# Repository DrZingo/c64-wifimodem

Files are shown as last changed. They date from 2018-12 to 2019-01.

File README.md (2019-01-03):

# c64-wifimodem

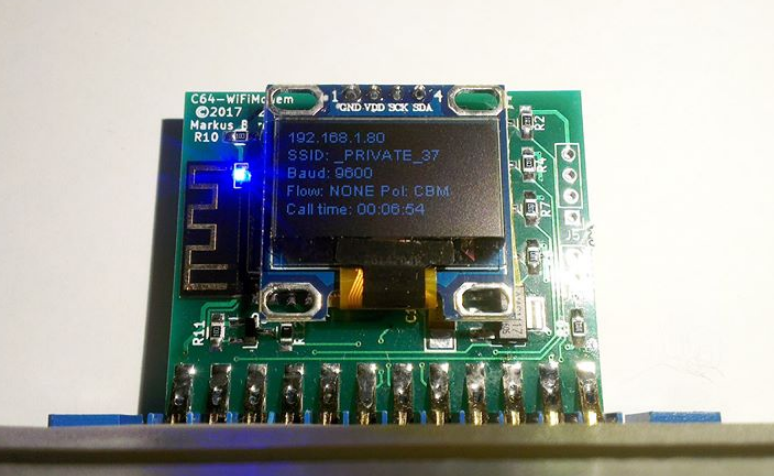
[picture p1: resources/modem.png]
modem


## src
Source code for my c64-wifimodem

Feel free to make changes and correction.

## Important
- Please change example.com to your own domain for OTA updates. 
- You will also have to create a backend for OTA to work.

## Stuff that needs work
- Changing pin polarity does not work as expected.
  - V-1541 and commodoreserver.com should work if implemented correct. I had it working, but then normal cbm polarity didn't work as it should.
- Higher baud rates
  - 19200 and 38400 will work but is only used with flipped polarity as I know of.
- Incoming calls
  - I am not enough familiar with bbs servers answering mechanism, and couldn't get it to work with my badly set up bbs server.
  - Direct call connection to the modem does work, sort of.
- S-registers
  - May be useful, I don't know.

## c64-wifimodem
PCB files in kicad format. Nothing much to say about it.

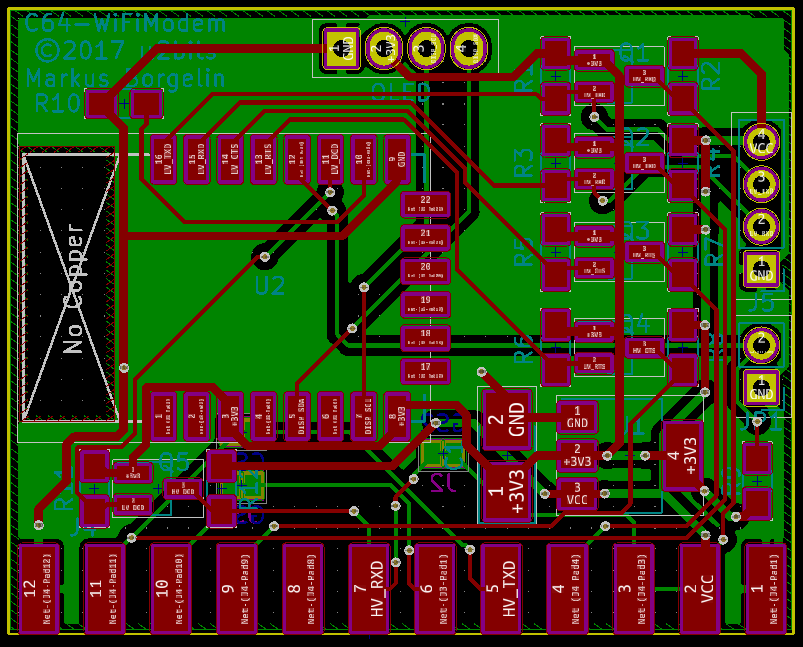
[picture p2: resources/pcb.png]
pcb


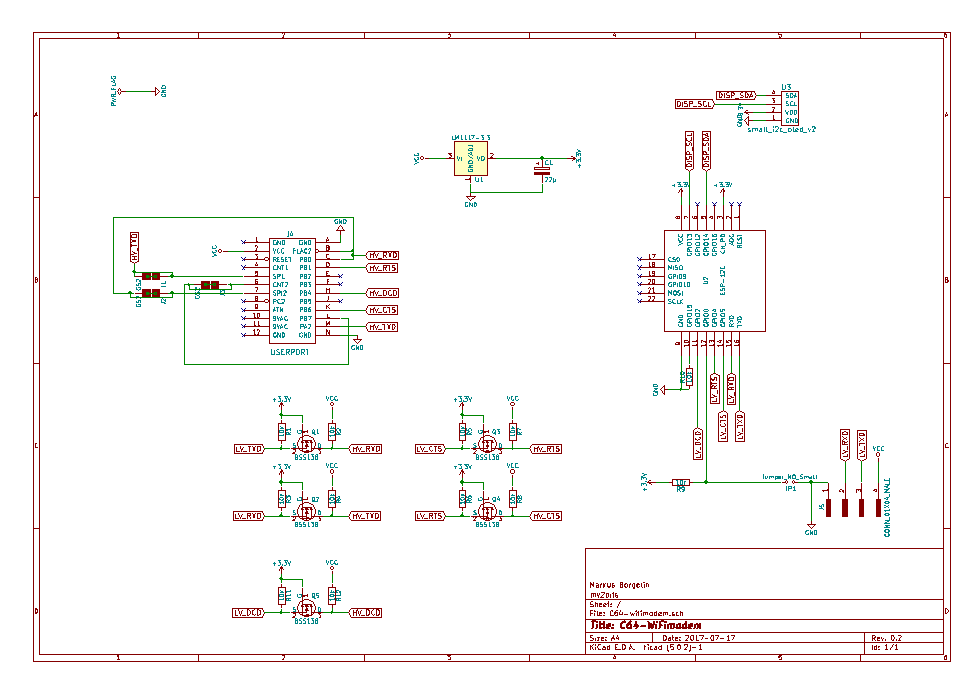
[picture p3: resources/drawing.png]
schematic


## BOM

```
 C1      Tantalum 22uF Case B, 3528
 J4      User Port edge connector
 Q1-Q5   BSS138 SOT-23
 R1-R12  10k 0805
 U1      LM1117-3.3 SOT-223
 U2      ESP8266 12E or 12F
 U3      OLED 0.96" GND,VCC,SCL,SDA
```

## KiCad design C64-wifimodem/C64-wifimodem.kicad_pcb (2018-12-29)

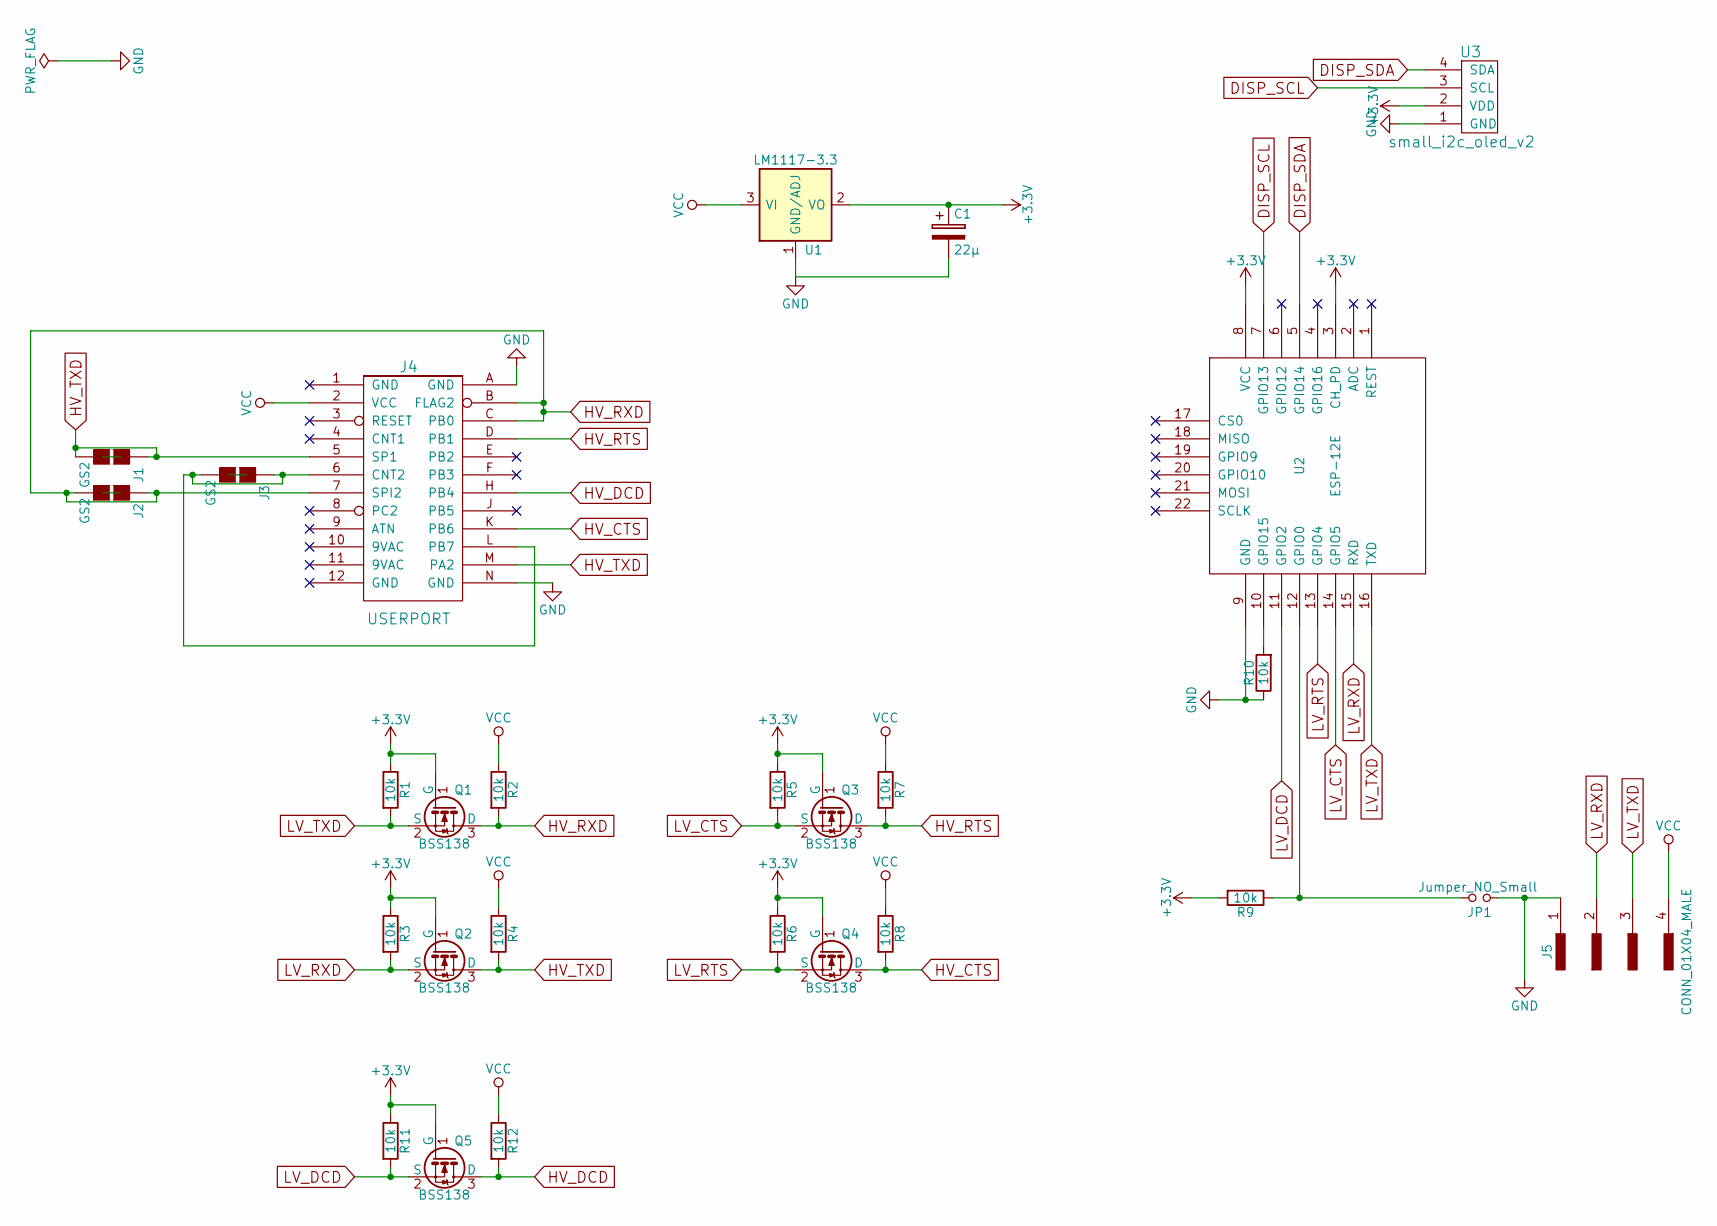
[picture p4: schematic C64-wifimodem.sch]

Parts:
C1: 22µ; CP_Tantalum_Case-B_EIA-3528-21_Hand
J1, J2, J3: GS2
J4: USERPORT
J5: CONN_01X04_MALE; Pin_Header_Straight_1x04_Pitch2.54mm
JP1: Jumper_NO_Small; Pin_Header_Straight_1x02_Pitch2.54mm
Q1, Q2, Q3, Q4, Q5: BSS138; SOT-23_Handsoldering
R1, R2, R3, R4, R5, R6, R7, R8, R9, R10, R11, R12: 10k; R_0805_HandSoldering
U1: LM1117-3.3; SOT-223
U2: ESP-12E; ESP-12E_SMD_wo_line
U3: small_i2c_oled_v2; Small_I2C_OLED_v2

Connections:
+3V3: C1.1, Q1.1 (G), Q2.1 (G), Q3.1 (G), Q4.1 (G), Q5.1 (G), R1.1, R3.1, R5.1, R6.1, R9.2, R11.1, U1.2 (VO), U1.4 (VO), U2.3 (CH_PD), U2.8 (VCC), U3.2 (VDD)
DISP_SCL: U2.7 (GPIO13), U3.3 (SCL)
DISP_SDA: U2.5 (GPIO14), U3.4 (SDA)
GND: C1.2, J4.A (GND), J4.N (GND), J5.1, JP1.1, R10.1, U1.1 (GND/ADJ), U2.9 (GND), U3.1 (GND)
HV_CTS: J4.K (PB6), Q4.3 (D), R8.2
HV_DCD: J4.H (PB4), Q5.3 (D), R12.2
HV_RTS: J4.D (PB1), Q3.3 (D), R7.2
HV_RXD: J2.1 (G1), J2.2 (G2), J4.7 (SPI2), J4.B (FLAG2), J4.C (PB0), Q1.3 (D), R2.2
HV_TXD: J1.1 (G1), J1.2 (G2), J4.5 (SP1), J4.M (PA2), Q2.3 (D), R4.2
LV_CTS: Q3.2 (S), R5.2, U2.14 (GPIO5)
LV_DCD: Q5.2 (S), R11.2, U2.11 (GPIO2)
LV_RTS: Q4.2 (S), R6.2, U2.13 (GPIO4)
LV_RXD: J5.2, Q2.2 (S), R3.2, U2.15 (RXD)
LV_TXD: J5.3, Q1.2 (S), R1.2, U2.16 (TXD)
unnamed: J3.1 (G1), J3.2 (G2), J4.6 (CNT2), J4.L (PB7)
unnamed: JP1.2, R9.1, U2.12 (GPIO0)
unnamed: R10.2, U2.10 (GPIO15)
VCC: J4.2 (VCC), J5.4, R2.1, R4.1, R7.1, R8.1, R12.1, U1.3 (VI)

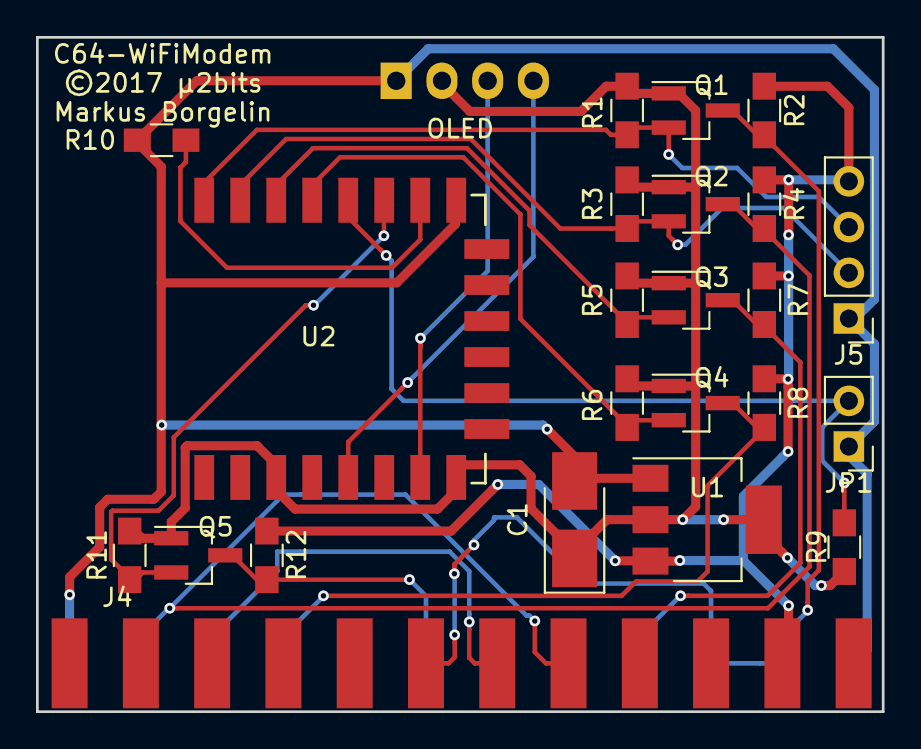
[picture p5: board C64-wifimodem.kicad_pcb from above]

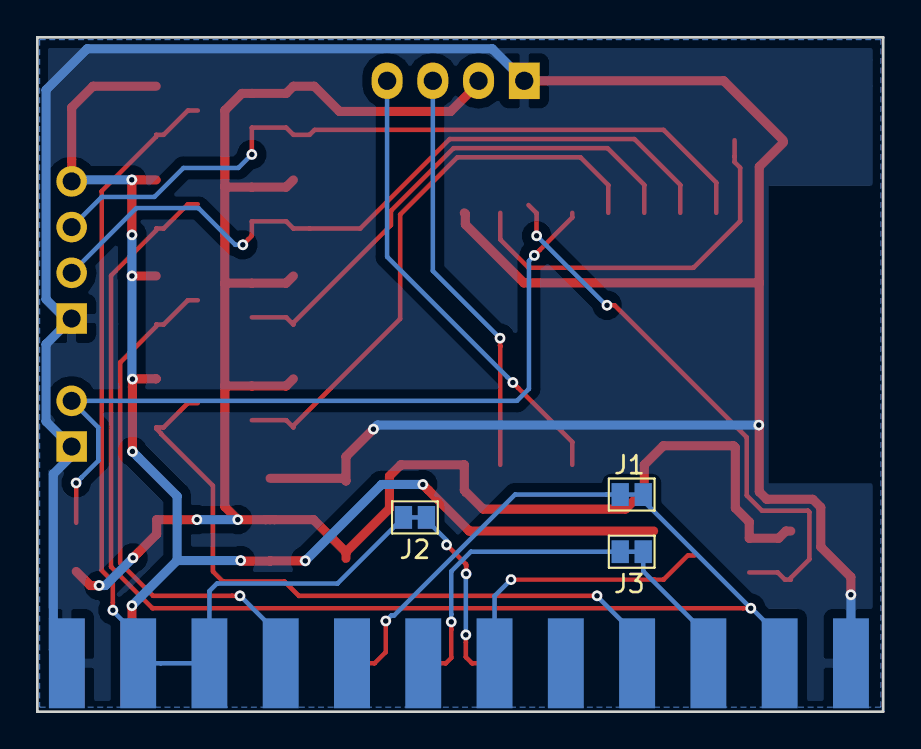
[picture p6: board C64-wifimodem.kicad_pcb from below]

Board: 2 copper layers, 47.0 x 37.5 mm, 27 parts (3 on the bottom side), 18 nets.

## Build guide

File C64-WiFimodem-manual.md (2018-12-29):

# C64-WiFimodem instructions

This is a WiFi modem for your Commodore 64 and the modern era of internet connectivity.

## Release history
2017-12-01 (online manual update)
* Added info for unencrypted WiFi

2017-09-16 (v0.1.9)
* Small typo correction. Update not necessary

2017-09-09 (online manual update)
* Added 'Hints and Tips' to manual

2017-09-06 (online manual update)
* Added pre-0.1.8 notice to 'Configure WiFi' section in manual

2017-08-30 (v0.1.8 - First release)
* The first available firmware loaded with features.
* Polarity is very experimental at the moment, and your modem will most probably stop responding if you change it. It will not harm your modem nor your computer, but you will have to reboot.
* To have a BBS Server, you will probably need RI-signal, which this modem does not supply. I will have to look further into this. But you can call from one terminal to another, i.e. someone calls you at your server port while you are in a terminal.

## Installation
1. First power off your Commodore. 
2. Plug C64-WiFimodem in the User Port of your C64.
3. Start your C64 and load a terminal program, preferrable [CCGMS 2017 V6], which is the terminal supported by this modem.
4. Now you should see the modem display telling you to press Return.
5. Change your terminal to ASCII mode and 300 baud. 

   Press ```F7``` to enter CCGMS settings.  
   Press ```B``` a couple of times until baud shows '300'.  
   Then press ```RETURN``` to go back to terminal mode.  
   Back in terminal mode you press ```F8``` (Shift+F7) to change to Anscii.
6. Press ```RETURN```, and you should see a welcome message in your C64 terminal.
7. type ```AT?``` and you should see some help.

## Configure WiFi

First type
```
AT$SCAN<RETURN>
```
to see all avaliable WiFi networks

Be aware that some characters show up differently on your Commodore screen. For instance underscore ```'_'``` will show up as left arrow ```'⬅'```. This is also how you have to type it in on your Commodore.

Then type
```
AT$SSID=<Your SSID here as shown in the SCAN listing><RETURN>
AT$PASS=<Your SSID password here><RETURN>
```
If you are connecting to a WiFi without encryption, just put anything in AT$PASS, it can not be empty. E.g. ```AT$PASS=123```

Now type
```
AT$C1<RETURN>
```
pre-0.1.8 use ATC1 instead
```
ATC1<RETURN>
```
and the modem will try to connect to the specified router. It may fail to connect the first time which is normal. Just try again, and if it won't connect, check for typos in your SSID or password.

Now when you have connected, you can save your settings with
```
AT&W<RETURN>
```
The modem will now try to connect to this network every time you start your Commodore and send the first ```RETURN``` to it.

## Extra configuration

If you prefer to have for example 2400 baud at startup, follow these commands:
```
AT$SB=2400<RETURN>
```
This will change the modem to 2400 baud. Now press ```F7``` to go to Terminal settings. 
Change terminal baud-rate with ```B``` to 2400. You may also have to change "Modem Type" to either "User Port 300-2400" or "UP9600" with ```M``` a couple of times. I use UP9600 most of the time.
Now press ```<RETURN>``` to go back to Terminal Mode.
Test with
```
AT<RETURN>
```
You will see "OK". If there was some garbage in the buffer it will give you "ERROR". Just try again.
Now type
```
AT&W
```
This will store your settings to the modem. Then press ```F7``` again and then ```S``` to save your terminal settings.

## Hints and Tips

If you experience graphics tearing in UP9600 mode, you can try using hardware handshake.
In offline mode type:
```
at&k1<RETURN>
```
Or in online mode type:
```
+++ (NO RETURN, wait for 'ok', and you are in cmd mode)
at&k1<RETURN>
ato<RETURN> (going back to online mode)
```
If you experience lockups while changing baud rates, always set UP9600 as modem type first. You can use UP9600 for 300-9600 baud, so there is no need to use other modem types.
Press ```<F7>``` to enter CCGMS settings.
Press ```M``` to set UP9600.
Press ```RETURN``` to go back to terminal mode.

Please have hardware handshaking off, while changing baudrate, and preferrable be in Graphics mode, not Anscii. This will minimize possible modem lockups.
Example:
```
at&k0<RETURN>
<F8 to get to Graphics mode>
at$sb=9600
at&k1<RETURN>
```

## Commands

| DIALING COMMANDS | Explanation | Example |
| --- | --- | --- |
| ATDTHOST:PORT | Dial a host | ```ATDTBBS.RETROHACK.SE:6464``` |
| ATDSN (0-9) | Dial a stored host | ```ATDS1``` |
| AT&ZN=HOST:PORT | Store a host and port to speed dials where N is a number from 0 to 9 | ```AT&Z1=BBS.RETROHACK.SE:6464``` |
| ATH | Hangup from a connected call | ```ATH``` |
| +++ | Enter command mode from online mode | ```+++``` |
| ATO | Exit command mode and go to online mode again | ```ATO``` |

| SERVER COMMANDS | Explanation | Example |
| --- | --- | --- |
| ATA | Answer an incoming call manually | ```ATA``` |
| AT$SP=N | Set the port where callers will reach you | ```AT$SP=6400``` |
| ATS0/ATS1 | Set auto answer, OFF/ON | ```ATS0``` |
| AT$BM=MESSAGE | Set the message that callers will see when your server is busy | ```AT$BM=SORRY, THE SERVER IS CURRENTLY BUSY. PLEASE TRY LATER.``` |

| INFO | Explanation | Example |
| ---- | --- | --- |
| ATI | Show modem info | ```ATI``` |

| GENERAL SETTINGS | Explanation | Example |
| --- | --- | --- |
| AT$SB=N (300-38400) | Set the modem baud rate | ```AT$SB=2400``` |
| AT&PN (0=CBM,1=NORM) | Set the pin polarity to commodore or normal | ```AT&P0``` |
| AT&KN (0=NONE,1=HW) | Set the flow control to none or hardware | ```AT&K0``` |
| ATE0/ATE1 | Set the modem to echo back to terminal, OFF/ON | ```ATE1``` |
| ATV0/ATV1 | Set verbose modem responds, OFF/ON | ```ATV1``` |
| ATZ | Load settings from flash | ```ATZ``` |
| AT&W | Write current settings to flash | ```AT&W``` |
| AT&V | View current and stored settings | ```AT&V``` |
| AT&F | Restore modem to factory defaults | ```AT&F``` |

| WIFI SETTINGS | Explanation | Example |
| --- | --- | --- |
| AT$C0/AT$C1 | Disconnect from wifi / Connect to wifi | ```AT$C1``` (old firmware ```ATC1``` and ```ATC0```) |
| AT$SSID=[SSID] | Set the wifi SSID to connect to. The common underscore is a left arrow on c64. See ```HOME_ROUTER``` in example. | ```AT$SSID=HOME⬅ROUTER``` |
| AT$PASS=PASS | Set the wifi password of the SSID you are connecting to. Your terminal have to be in ASCII/Anscii mode, and some characters may show differently in your terminal. For instance, underscore '_' will show as left arrow '⬅'. Some characters may not even work. Give it some trial and error, and if it won't work, please change your routers password to less obscure characters. | ```AT$PASS=S3cr3tP4ssw0rd``` | 
| AT$SCAN | The modem scans for available wifi SSIDs you can connect to. Password enabled networks will have an asterisk (*) suffix. This will show you what characters to enter when setting up with AT$SSID. | ```AT$SCAN``` |

| OTHER COMMANDS | Explanation | Example |
| --- | --- | --- |
| AT$UPDATE | Downloads and updates the firmware to the latest version. Updates will sometimes restore the settings to default values. This happens when an update adds fuctionality that needs to reorganize the stored settings. Please restart your modem after update (```AT$RESTART```).  | ```AT$UPDATE``` |
| AT$RESTART | Restarts the modem and loads the stored settings. Remember to change the terminal settings according to your stored settings afterwards. | ```AT$RESTART``` |
| ATCOMMAND? | Shows the current settings of specified command. | ```AT&K?```  ```ATE?``` |

## License

All files are licensed under GPLv3

---
©2017 µ2bits, Markus Borgelin

[//]: # (Referencer m.m.)

[CCGMS 2017 V6]: <http://csdb.dk/release/?id=156523>

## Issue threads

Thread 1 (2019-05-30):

ESP32 port

kd8bxp, 2019-05-30:
Hi, I just wanted to let you know that I ported the code over to a ESP32 - using a TTGO T-Eight board with OLED (there are at least two different boards called T-Eight from TTGO/LilyGo so depending on which board you have you might need to change/update the OLED pin numbers)
Mostly the code was easy to port and use - I ran into a issue with the telnet server - and it's not working, I'm not real sure how to make that work.
But if you are or anyone is interested in using a ESP32 - this might be a good place to started and fix my port :-)
https://github.com/kd8bxp/c64-wifimodem/tree/esp32
Also, I'm using this to get my Tandy 102 on WiFi, and I think it will also work with my Apple IIc, but I'll have to make a cable for that.
I am planning on making a edge connector to 9 pin serial so I can also use this with my C64. :-)
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

DrZingo, 2019-05-31:
Great!
I hope you get some help with your port. I have no possibility to test myself, and therefore I will not merge it into my repo. Thanks anyway, always great to see the retro scene thrive. :)

kd8bxp, 2019-05-31:
No problem, I understand - I hope someone can help, I'd like to get telnet working. Have a great day, and thanks for original code, and inspiration to build mine.

Closed 2019-05-31.

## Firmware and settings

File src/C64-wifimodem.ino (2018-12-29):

/*
   Change example.com to your needs.
   You will also have to create your own backend for updates.


   C64-WiFiModem - (c) 2017 my2bits <markus at borgelin.org>
   changes here
   Built hardware based on ESP-12, 3.3V-reg and level shifters.
   Tidy up help, and categorizing
   Added automatic firmware check at startup
   Corrected connectWifi() link check
   Changed MAX_CMD_LENGTH to actual FIFO buffer size
   Fixed help-bug in 9600+ baud
   Corrected setBaudRate(), bauds[] array and sizeof, to error out correct
   Adjusted pinouts for my needs
   Adjusted default servers
   Added modem restart command
   Added OLED display with information
   Added OTA Update
   Added scan for wifi
   Some fixes to Pin polarity, does not work as expected though. Fixes welcome
   Probably added more stuff I forgot to write here.
   Thanks to Paul Richards and Jussi Salin for source code.

   based on
   WiFi SIXFOUR - A virtual WiFi modem based on the ESP 8266 chipset
   Copyright (C) 2016 Paul Rickards <rickards@gmail.com>
   Added EEPROM read/write, status/help pages, busy answering of incoming calls
   uses the readily available Sparkfun ESP8266 WiFi Shield which has 5v level
   shifters and 3.3v voltage regulation present-- easily connect to a C64
   https://www.sparkfun.com/products/13287

   based on
   ESP8266 based virtual modem
   Copyright (C) 2016 Jussi Salin <salinjus@gmail.com>

   https://github.com/jsalin/esp8266_modem

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
   You should have received a copy of the GNU General Public License
   along with this program.  If not, see <http://www.gnu.org/licenses/>.
*/

#include <ESP8266WiFi.h>
#include <ESP8266WebServer.h>
#include <EEPROM.h>
#include <ESP8266mDNS.h>

// OTA stuff
//#include <ESP8266WiFiMulti.h>
#include <ESP8266HTTPClient.h>
#include <ESP8266httpUpdate.h>
//ESP8266WiFiMulti WiFiMulti;
// OTA stuff end

// OLED stuff
//#include <Wire.h>  // Only needed for Arduino 1.6.5 and earlier
//#include "SSD1306.h" // alias for `#include "SSD1306Wire.h"
#include "SSD1306Brzo.h"
//#define OLED_RESET LED_BUILTIN // Changed reset pin to LED_BUILTIN to be able to use D4,D5
//SSD1306 display(0x3c, D4, D5); // Initialize the OLED display using Wire library. ADDR,SDA,SCL
SSD1306Brzo display(0x3c, D5, D7); //TODO: Free up a pin. D5,D7...
// OLED stuff end
/*
// These translation tables are not used yet.
static unsigned char petToAscTable[256] = {
0x00,0x01,0x02,0x03,0x04,0x05,0x06,0x07,0x14,0x09,0x0d,0x11,0x93,0x0a,0x0e,0x0f,
0x10,0x0b,0x12,0x13,0x08,0x15,0x16,0x17,0x18,0x19,0x1a,0x1b,0x1c,0x1d,0x1e,0x1f,
0x20,0x21,0x22,0x23,0x24,0x25,0x26,0x27,0x28,0x29,0x2a,0x2b,0x2c,0x2d,0x2e,0x2f,
0x30,0x31,0x32,0x33,0x34,0x35,0x36,0x37,0x38,0x39,0x3a,0x3b,0x3c,0x3d,0x3e,0x3f,
0x40,0x61,0x62,0x63,0x64,0x65,0x66,0x67,0x68,0x69,0x6a,0x6b,0x6c,0x6d,0x6e,0x6f,
0x70,0x71,0x72,0x73,0x74,0x75,0x76,0x77,0x78,0x79,0x7a,0x5b,0x5c,0x5d,0x5e,0x5f,
0xc0,0xc1,0xc2,0xc3,0xc4,0xc5,0xc6,0xc7,0xc8,0xc9,0xca,0xcb,0xcc,0xcd,0xce,0xcf,
0xd0,0xd1,0xd2,0xd3,0xd4,0xd5,0xd6,0xd7,0xd8,0xd9,0xda,0xdb,0xdc,0xdd,0xde,0xdf,
0x80,0x81,0x82,0x83,0x84,0x85,0x86,0x87,0x88,0x89,0x8a,0x8b,0x8c,0x8d,0x8e,0x8f,
0x90,0x91,0x92,0x0c,0x94,0x95,0x96,0x97,0x98,0x99,0x9a,0x9b,0x9c,0x9d,0x9e,0x9f,
0xa0,0xa1,0xa2,0xa3,0xa4,0xa5,0xa6,0xa7,0xa8,0xa9,0xaa,0xab,0xac,0xad,0xae,0xaf,
0xb0,0xb1,0xb2,0xb3,0xb4,0xb5,0xb6,0xb7,0xb8,0xb9,0xba,0xbb,0xbc,0xbd,0xbe,0xbf,
0x60,0x41,0x42,0x43,0x44,0x45,0x46,0x47,0x48,0x49,0x4a,0x4b,0x4c,0x4d,0x4e,0x4f,
0x50,0x51,0x52,0x53,0x54,0x55,0x56,0x57,0x58,0x59,0x5a,0x7b,0x7c,0x7d,0x7e,0x7f,
0xa0,0xa1,0xa2,0xa3,0xa4,0xa5,0xa6,0xa7,0xa8,0xa9,0xaa,0xab,0xac,0xad,0xae,0xaf,
0xb0,0xb1,0xb2,0xb3,0xb4,0xb5,0xb6,0xb7,0xb8,0xb9,0xba,0xbb,0xbc,0xbd,0xbe,0xbf
};

static unsigned char ascToPetTable[256] = {
0x00,0x01,0x02,0x03,0x04,0x05,0x06,0x07,0x14,0x09,0x0d,0x11,0x93,0x0a,0x0e,0x0f,
0x10,0x0b,0x12,0x13,0x08,0x15,0x16,0x17,0x18,0x19,0x1a,0x1b,0x1c,0x1d,0x1e,0x1f,
0x20,0x21,0x22,0x23,0x24,0x25,0x26,0x27,0x28,0x29,0x2a,0x2b,0x2c,0x2d,0x2e,0x2f,
0x30,0x31,0x32,0x33,0x34,0x35,0x36,0x37,0x38,0x39,0x3a,0x3b,0x3c,0x3d,0x3e,0x3f,
0x40,0xc1,0xc2,0xc3,0xc4,0xc5,0xc6,0xc7,0xc8,0xc9,0xca,0xcb,0xcc,0xcd,0xce,0xcf,
0xd0,0xd1,0xd2,0xd3,0xd4,0xd5,0xd6,0xd7,0xd8,0xd9,0xda,0x5b,0x5c,0x5d,0x5e,0x5f,
0xc0,0x41,0x42,0x43,0x44,0x45,0x46,0x47,0x48,0x49,0x4a,0x4b,0x4c,0x4d,0x4e,0x4f,
0x50,0x51,0x52,0x53,0x54,0x55,0x56,0x57,0x58,0x59,0x5a,0xdb,0xdc,0xdd,0xde,0xdf,
0x80,0x81,0x82,0x83,0x84,0x85,0x86,0x87,0x88,0x89,0x8a,0x8b,0x8c,0x8d,0x8e,0x8f,
0x90,0x91,0x92,0x0c,0x94,0x95,0x96,0x97,0x98,0x99,0x9a,0x9b,0x9c,0x9d,0x9e,0x9f,
0xa0,0xa1,0xa2,0xa3,0xa4,0xa5,0xa6,0xa7,0xa8,0xa9,0xaa,0xab,0xac,0xad,0xae,0xaf,
0xb0,0xb1,0xb2,0xb3,0xb4,0xb5,0xb6,0xb7,0xb8,0xb9,0xba,0xbb,0xbc,0xbd,0xbe,0xbf,
0x60,0x61,0x62,0x63,0x64,0x65,0x66,0x67,0x68,0x69,0x6a,0x6b,0x6c,0x6d,0x6e,0x6f,
0x70,0x71,0x72,0x73,0x74,0x75,0x76,0x77,0x78,0x79,0x7a,0x7b,0x7c,0x7d,0x7e,0x7f,
0xe0,0xe1,0xe2,0xe3,0xe4,0xe5,0xe6,0xe7,0xe8,0xe9,0xea,0xeb,0xec,0xed,0xee,0xef,
0xf0,0xf1,0xf2,0xf3,0xf4,0xf5,0xf6,0xf7,0xf8,0xf9,0xfa,0xfb,0xfc,0xfd,0xfe,0xff
};
*/
#define VERSIONA 0
#define VERSIONB 1
#define VERSION_ADDRESS 0    // EEPROM address
#define VERSION_LEN     2    // Length in bytes
#define SSID_ADDRESS    2
#define SSID_LEN        32
#define PASS_ADDRESS    34
#define PASS_LEN        63
#define IP_TYPE_ADDRESS 97   // for future use
#define STATIC_IP_ADDRESS 98 // length 4, for future use
#define STATIC_GW       102  // length 4, for future use
#define STATIC_DNS      106  // length 4, for future use
#define STATIC_MASK     110  // length 4, for future use
#define BAUD_ADDRESS    111
#define ECHO_ADDRESS    112
#define SERVER_PORT_ADDRESS 113 // 2 bytes
#define AUTO_ANSWER_ADDRESS 115 // 1 byte
#define TELNET_ADDRESS  116     // 1 byte
#define VERBOSE_ADDRESS 117
#define PET_TRANSLATE_ADDRESS 118
#define FLOW_CONTROL_ADDRESS 119
#define PIN_POLARITY_ADDRESS 120
#define DIAL0_ADDRESS   200
#define DIAL1_ADDRESS   250
#define DIAL2_ADDRESS   300
#define DIAL3_ADDRESS   350
#define DIAL4_ADDRESS   400
#define DIAL5_ADDRESS   450
#define DIAL6_ADDRESS   500
#define DIAL7_ADDRESS   550
#define DIAL8_ADDRESS   600
#define DIAL9_ADDRESS   650
#define BUSY_MSG_ADDRESS 700
#define BUSY_MSG_LEN    80
#define LAST_ADDRESS    780

#define SWITCH_PIN 0        // GPIO0 (programming mode pin)
#define LED_PIN 12          // Status LED
#define DCD_PIN 2           // DCD Carrier Status
#define RTS_PIN 4           // RTS Request to Send, connect to host's CTS pin
#define CTS_PIN 5           // CTS Clear to Send, connect to host's RTS pin
#define DISP_SDA 14         // Display SDA pin
#define DISP_SCL 13         //Display SCL pin

// Global variables
String build = "9";
String firmwareVersion =  "C64-wifimodem-" +  String(VERSIONA) + "." + String(VERSIONB) + "." + build;
String cmd = "";           // Gather a new AT command to this string from serial
bool cmdMode = true;       // Are we in AT command mode or connected mode
bool callConnected = false;// Are we currently in a call
bool telnet = false;       // Is telnet control code handling enabled
bool verboseResults = false;
//#define DEBUG 1          // Print additional debug information to serial channel
#undef DEBUG
#define LISTEN_PORT 6400   // Listen to this if not connected. Set to zero to disable.
int tcpServerPort = LISTEN_PORT;
#define RING_INTERVAL 3000 // How often to print RING when having a new incoming connection (ms)
unsigned long lastRingMs = 0; // Time of last "RING" message (millis())
//long myBps;                // What is the current BPS setting
#define MAX_CMD_LENGTH 128 // Maximum length for AT command
char plusCount = 0;        // Go to AT mode at "+++" sequence, that has to be counted
unsigned long plusTime = 0;// When did we last receive a "+++" sequence
#define LED_TIME 15         // How many ms to keep LED on at activity
unsigned long ledTime = 0;
#define TX_BUF_SIZE 256    // Buffer where to read from serial before writing to TCP
// (that direction is very blocking by the ESP TCP stack,
// so we can't do one byte a time.)
uint8_t txBuf[TX_BUF_SIZE];
const int speedDialAddresses[] = { DIAL0_ADDRESS, DIAL1_ADDRESS, DIAL2_ADDRESS, DIAL3_ADDRESS, DIAL4_ADDRESS, DIAL5_ADDRESS, DIAL6_ADDRESS, DIAL7_ADDRESS, DIAL8_ADDRESS, DIAL9_ADDRESS };
String speedDials[10];
const long bauds[] = { 300, 1200, 2400, 4800, 9600, 19200, 38400 }; // not needed yet  57600, 115200
byte serialspeed;
bool echo = true;
bool autoAnswer = false;
String ssid, password, busyMsg;
byte ringCount = 0;
String resultCodes[] = { "OK", "CONNECT", "RING", "NO CARRIER", "ERROR", "", "NO DIALTONE", "BUSY", "NO ANSWER" };
enum resultCodes_t { R_OK, R_CONNECT, R_RING, R_NOCARRIER, R_ERROR, R_NONE, R_NODIALTONE, R_BUSY, R_NOANSWER };
unsigned long connectTime = 0;
bool petTranslate = false; // Fix PET MCTerm 1.26C Pet->ASCII encoding to actual ASCII
bool hex = false;
enum flowControl_t { F_NONE, F_HARDWARE, F_SOFTWARE };
byte flowControl = F_NONE;      // Use flow control
bool txPaused = false;          // Has flow control asked us to pause?
enum pinPolarity_t { P_CBM, P_NORMAL }; // Is LOW (0) or HIGH (1) active?
byte pinPolarity = P_CBM;
bool ota_flag = false;  // Start OTA in main loop

// Telnet codes
#define DO 0xfd
#define WONT 0xfc
#define WILL 0xfb
#define DONT 0xfe



WiFiClient tcpClient;
WiFiServer tcpServer(tcpServerPort);
ESP8266WebServer webServer(80);
MDNSResponder mdns;

/*---------------------------------------------------------------------- */

String connectTimeString() {
    unsigned long now = millis();
    int secs = (now - connectTime) / 1000;
    int mins = secs / 60;
    int hours = mins / 60;
    String out = "";
    if (hours < 10) out.concat("0");
    out.concat(String(hours));
    out.concat(":");
    if (mins % 60 < 10) out.concat("0");
    out.concat(String(mins % 60));
    out.concat(":");
    if (secs % 60 < 10) out.concat("0");
    out.concat(String(secs % 60));
    return out;
}

void writeSettings() {
    setEEPROM(ssid, SSID_ADDRESS, SSID_LEN);
    setEEPROM(password, PASS_ADDRESS, PASS_LEN);
    setEEPROM(busyMsg, BUSY_MSG_ADDRESS, BUSY_MSG_LEN);

    EEPROM.write(BAUD_ADDRESS, serialspeed);
    EEPROM.write(ECHO_ADDRESS, byte(echo));
    EEPROM.write(AUTO_ANSWER_ADDRESS, byte(autoAnswer));
    EEPROM.write(SERVER_PORT_ADDRESS, highByte(tcpServerPort));
    EEPROM.write(SERVER_PORT_ADDRESS + 1, lowByte(tcpServerPort));
    EEPROM.write(TELNET_ADDRESS, byte(telnet));
    EEPROM.write(VERBOSE_ADDRESS, byte(verboseResults));
    EEPROM.write(PET_TRANSLATE_ADDRESS, byte(petTranslate));
    EEPROM.write(FLOW_CONTROL_ADDRESS, byte(flowControl));
    EEPROM.write(PIN_POLARITY_ADDRESS, byte(pinPolarity));

    for (int i = 0; i < 10; i++) {
        setEEPROM(speedDials[i], speedDialAddresses[i], 50);
    }
    EEPROM.commit();
}

void readSettings() {
    echo = EEPROM.read(ECHO_ADDRESS);
    autoAnswer = EEPROM.read(AUTO_ANSWER_ADDRESS);
    // serialspeed = EEPROM.read(BAUD_ADDRESS);

    ssid = getEEPROM(SSID_ADDRESS, SSID_LEN);
    password = getEEPROM(PASS_ADDRESS, PASS_LEN);
    busyMsg = getEEPROM(BUSY_MSG_ADDRESS, BUSY_MSG_LEN);
    tcpServerPort = word(EEPROM.read(SERVER_PORT_ADDRESS), EEPROM.read(SERVER_PORT_ADDRESS + 1));
    telnet = EEPROM.read(TELNET_ADDRESS);
    verboseResults = EEPROM.read(VERBOSE_ADDRESS);
    petTranslate = EEPROM.read(PET_TRANSLATE_ADDRESS);
    flowControl = EEPROM.read(FLOW_CONTROL_ADDRESS);
    pinPolarity = EEPROM.read(PIN_POLARITY_ADDRESS);

    for (int i = 0; i < 10; i++) {
        speedDials[i] = getEEPROM(speedDialAddresses[i], 50);
    }
}

void defaultEEPROM() {
    EEPROM.write(VERSION_ADDRESS, VERSIONA);
    EEPROM.write(VERSION_ADDRESS + 1, VERSIONB);

    setEEPROM("", SSID_ADDRESS, SSID_LEN);
    setEEPROM("", PASS_ADDRESS, PASS_LEN);
    setEEPROM("d", IP_TYPE_ADDRESS, 1);
    EEPROM.write(SERVER_PORT_ADDRESS, highByte(LISTEN_PORT));
    EEPROM.write(SERVER_PORT_ADDRESS + 1, lowByte(LISTEN_PORT));

    EEPROM.write(BAUD_ADDRESS, 0x00);
    EEPROM.write(ECHO_ADDRESS, 0x01);
    EEPROM.write(AUTO_ANSWER_ADDRESS, 0x01);
    EEPROM.write(TELNET_ADDRESS, 0x00);
    EEPROM.write(VERBOSE_ADDRESS, 0x01);
    EEPROM.write(PET_TRANSLATE_ADDRESS, 0x00);
    EEPROM.write(FLOW_CONTROL_ADDRESS, 0x00);
    EEPROM.write(PIN_POLARITY_ADDRESS, 0x00);

    setEEPROM("bbs.retrohack.se:6464", speedDialAddresses[0], 50);
    setEEPROM("deltacity.se:2323", speedDialAddresses[1], 50);
    setEEPROM("bbs.retrohack.se:8484", speedDialAddresses[2], 50);
    setEEPROM("borderlinebbs.dyndns.org:6400", speedDialAddresses[3], 50);
    setEEPROM("cottonwoodbbs.dyndns.org:6502", speedDialAddresses[4], 50);
    setEEPROM("eaglebird.ddns.net:2300", speedDialAddresses[5], 50);
    setEEPROM("bbs.jammingsignal.com:23", speedDialAddresses[6], 50);
    for (int i = 7; i < 10; i++) {
      setEEPROM("", speedDialAddresses[i], 50);
    }

    setEEPROM("SORRY, THE BBS IS CURRENTLY BUSY. PLEASE TRY AGAIN LATER.", BUSY_MSG_ADDRESS, BUSY_MSG_LEN);
    EEPROM.commit();
}

String getEEPROM(int startAddress, int len) {
    String myString;

    for (int i = startAddress; i < startAddress + len; i++) {
        if (EEPROM.read(i) == 0x00) {
            break;
        }
        myString += char(EEPROM.read(i));
      //Serial.print(char(EEPROM.read(i)));
    }
    //Serial.println();
    return myString;
}

void setEEPROM(String inString, int startAddress, int maxLen) {
    for (int i = startAddress; i < inString.length() + startAddress; i++) {
        EEPROM.write(i, inString[i - startAddress]);
        //Serial.print(i, DEC); Serial.print(": "); Serial.println(inString[i - startAddress]);
        //if (EEPROM.read(i) != inString[i - startAddress]) { Serial.print(" (!)"); }
        //Serial.println();
    }
    // null pad the remainder of the memory space
    for (int i = inString.length() + startAddress; i < maxLen + startAddress; i++) {
        EEPROM.write(i, 0x00);
        //Serial.print(i, DEC); Serial.println(": 0x00");
    }
}

void sendResult(int resultCode) {
    Serial.print("\r\n");
    if (verboseResults == 0) {
        Serial.println(resultCode);
        return;
    }
    if (resultCode == R_CONNECT) {
        Serial.print(String(resultCodes[R_CONNECT]) + " " + String(bauds[serialspeed]));
    } else if (resultCode == R_NOCARRIER) {
        Serial.print(String(resultCodes[R_NOCARRIER]) + " (" + connectTimeString() + ")");
    } else {
        Serial.print(String(resultCodes[resultCode]));
    }
    Serial.print("\r\n");
}

void sendString(String msg) {
    Serial.print("\r\n");
    Serial.print(msg);
    Serial.print("\r\n");
}

// Hold for 5 seconds to switch to 300 baud
// Slow flash: keep holding
// Fast flash: let go
int checkButton() {
    long time = millis();
    while (digitalRead(SWITCH_PIN) == LOW && millis() - time < 5000) {
        delay(250);
        digitalWrite(LED_PIN, !digitalRead(LED_PIN));
        yield();
    }
    if (millis() - time > 5000) {
        Serial.flush();
        Serial.end();
        serialspeed = 0;
        delay(100);
        Serial.begin(bauds[serialspeed]);
        sendResult(R_OK);
        while (digitalRead(SWITCH_PIN) == LOW) {
            delay(50);
            digitalWrite(LED_PIN, !digitalRead(LED_PIN));
            yield();
        }
        return 1;
    } else {
        return 0;
    }
}
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
void loop() {
    maintainDisplay();

    // Check flow control
    handleFlowControl();

    // Service the Web server
    webServer.handleClient();

    // Check to see if user is requesting rate change to 300 baud
    checkButton();

    // New unanswered incoming connection on server listen socket
    if (tcpServer.hasClient()) {
      handleIncomingConnection();
    }

    /**** AT command mode ****/
    if (cmdMode == true) {

        // In command mode - don't exchange with TCP but gather characters to a string
        if (Serial.available()) {
            char chr = Serial.read();

            if (petTranslate == true)
                // Fix PET MCTerm 1.26C Pet->ASCII encoding to actual ASCII
                if (chr > 127) chr-= 128;
            else
                // Convert uppercase PETSCII to lowercase ASCII (C64) in command mode only
                if ((chr >= 193) && (chr <= 218)) chr-= 96;

            // Return, enter, new line, carriage return.. anything goes to end the command
            if ((chr == '\n') || (chr == '\r')) {
                command();
            }
            // Backspace or delete deletes previous character
            else if ((chr == 8) || (chr == 127) || (chr == 20)) {
                cmd.remove(cmd.length() - 1);
                if (echo == true) {
                    Serial.write(chr);
                }
            }
            else {
                if (cmd.length() < MAX_CMD_LENGTH) cmd.concat(chr);
                if (echo == true) {
                    Serial.write(chr);
                }
                if (hex) {
                    Serial.print(chr, HEX);
                }
            }
        }
    }
    /**** Connected mode ****/
    else {
      // Transmit from terminal to TCP
      if (Serial.available())
      {
        led_on();

        // In telnet in worst case we have to escape every byte
        // so leave half of the buffer always free
        int max_buf_size;
        if (telnet == true)
          max_buf_size = TX_BUF_SIZE / 2;
        else
          max_buf_size = TX_BUF_SIZE;

        // Read from serial, the amount available up to
        // maximum size of the buffer
        size_t len = std::min(Serial.available(), max_buf_size);
        Serial.readBytes(&txBuf[0], len);

        // Enter command mode with "+++" sequence
        for (int i = 0; i < (int)len; i++)
        {
          if (txBuf[i] == '+') plusCount++; else plusCount = 0;
          if (plusCount >= 3)
          {
            plusTime = millis();
          }
          if (txBuf[i] != '+')
          {
            plusCount = 0;
          }
        }

        // Double (escape) every 0xff for telnet, shifting the following bytes
        // towards the end of the buffer from that point
        if (telnet == true)
        {
          for (int i = len - 1; i >= 0; i--)
          {
            if (txBuf[i] == 0xff)
            {
              for (int j = TX_BUF_SIZE - 1; j > i; j--)
              {
                txBuf[j] = txBuf[j - 1];
              }
              len++;
            }
          }
        }
        // Fix PET MCTerm 1.26C Pet->ASCII encoding to actual ASCII
        if (petTranslate == true) {
          for (int i = len - 1; i >= 0; i--) {
            if (txBuf[i] > 127) txBuf[i]-= 128;
          }
        }
        // Write the buffer to TCP finally
        tcpClient.write(&txBuf[0], len);
        yield();
      }

      // Transmit from TCP to terminal
      while (tcpClient.available() && txPaused == false)
      {
        led_on();
        uint8_t rxByte = tcpClient.read();

        // Is a telnet control code starting?
        if ((telnet == true) && (rxByte == 0xff))
        {
  #ifdef DEBUG
          Serial.print("<t>");
  #endif
          rxByte = tcpClient.read();
          if (rxByte == 0xff)
          {
            // 2 times 0xff is just an escaped real 0xff
            Serial.write(0xff); Serial.flush();
          }
          else
          {
            // rxByte has now the first byte of the actual non-escaped control code
  #ifdef DEBUG
            Serial.print(rxByte);
            Serial.print(",");
  #endif
            uint8_t cmdByte1 = rxByte;
            rxByte = tcpClient.read();
            uint8_t cmdByte2 = rxByte;
            // rxByte has now the second byte of the actual non-escaped control code
  #ifdef DEBUG
            Serial.print(rxByte); Serial.flush();
  #endif
            // We are asked to do some option, respond we won't
            if (cmdByte1 == DO)
            {
              tcpClient.write((uint8_t)255); tcpClient.write((uint8_t)WONT); tcpClient.write(cmdByte2);
            }
            // Server wants to do any option, allow it
            else if (cmdByte1 == WILL)
            {
              tcpClient.write((uint8_t)255); tcpClient.write((uint8_t)DO); tcpClient.write(cmdByte2);
            }
          }
  #ifdef DEBUG
          Serial.print("</t>");
  #endif
        }
        else
        {
          // Non-control codes pass through freely
          Serial.write(rxByte); yield(); Serial.flush(); yield();
        }
        handleFlowControl();
      }
    }

    // If we have received "+++" as last bytes from serial port and there
    // has been over a second without any more bytes
    if (plusCount >= 3)
    {
      if (millis() - plusTime > 1000)
      {
        //tcpClient.stop();
        cmdMode = true;
        sendResult(R_OK);
        plusCount = 0;
      }
    }

    // Go to command mode if TCP disconnected and not in command mode
    if ((!tcpClient.connected()) && (cmdMode == false) && callConnected == true)
    {
      cmdMode = true;
      sendResult(R_NOCARRIER);
      connectTime = 0;
      callConnected = false;
      setCarrier(callConnected);
      //if (tcpServerPort > 0) tcpServer.begin();
    }

    // Turn off tx/rx led if it has been lit long enough to be visible
    if (millis() - ledTime > LED_TIME) digitalWrite(LED_PIN, !digitalRead(LED_PIN)); // toggle LED state
}

/*------------------------------------------------------------------------- */

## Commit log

2018-12-29 Add kicad files
    [C64-wifimodem.kicad_pcb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]
2018-12-30 Add BOM
2019-01-03 Fix BOM

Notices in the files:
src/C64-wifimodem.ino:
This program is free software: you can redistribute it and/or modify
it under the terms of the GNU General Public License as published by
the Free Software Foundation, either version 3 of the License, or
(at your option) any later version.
